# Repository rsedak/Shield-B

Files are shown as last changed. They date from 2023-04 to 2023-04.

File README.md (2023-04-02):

[Croatian version](README_HR-HR.md).

Introduction
============

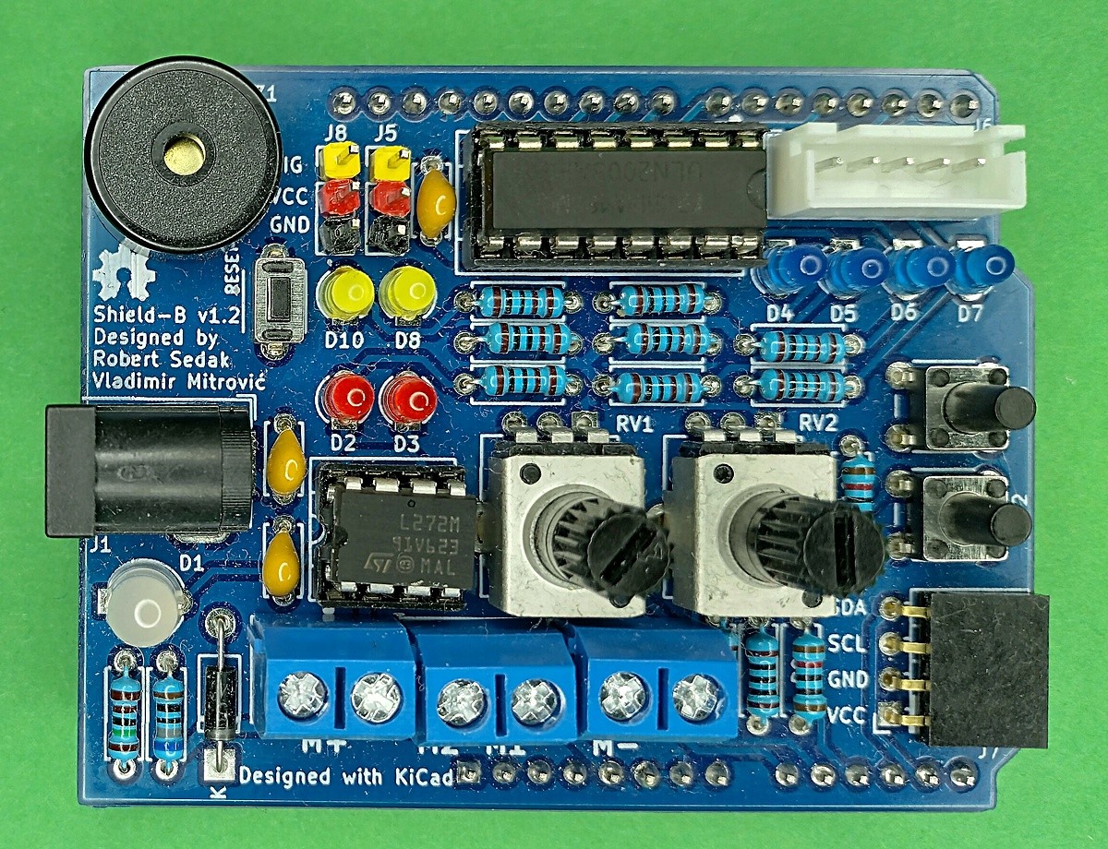
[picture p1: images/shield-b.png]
Shield application

Shield-B v1.2 is version of Arduino Uno based shield for student education compatible with BASCOM-AVR(C) and Arduino IDE.
During programming please keep in mind next design rules:
- D2, D4, D7, D8 — control step motor (J6)
- D5 — control DC motor (M1)
- D6 — control DC motor (M2)
- D9 — control servo motor (J5)
- D10 — control servo motor (J8)
- D13 — reserved for buzzer
- A0 — reserved for potentiometer RV1
- A1 — reserved for potentiometer RV2
- A2 — reserved for switch SW2 in INPUT_PULLUP mode
- A3 — reserved for switch SW3 INPUT_PULLUP mode
- A4,A5 — reserved for I2C communication with on board pull-up resistors (J7)

Contributors
------------
- Robert Sedak — features, Arduino expertise, schematic design, CAD design.
- Vladimir Mitrović — features, BASCOM-AVR expertise

Application
-----------
Robert Sedak made a video with examples programmed in Arduino IDE:

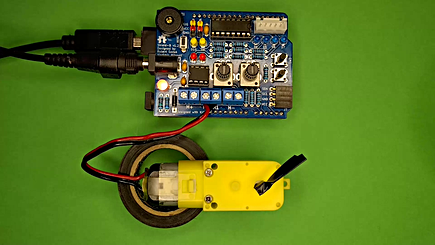
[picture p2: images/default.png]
Shield application (https://youtu.be/HcjEryUcfLM "Shield-B examples")


You can download examples for Arduino IDE from [here](examples/).

Bill Of Materials
-----------------
- 1 ea., PCB
- 1 ea., 680R ohm 1/4W 1% Resistor (R1)
- 8 ea., 1K ohm 1/4W 1% Resistor (R2-R8, R14)
- 2 ea., 10K ohm 1/4W 1% Resistor (R9, R10)
- 2 ea., 100R ohm 1/4W 1% Resistor (R11, R12)
- 1 ea., 1.5K ohm 1/4W 1% Resistor (R13)
- 1 ea., LED 5mm DUAL AKA (D1)
- 8 ea., LED 3mm (D2-D8, D10)
- 1 ea., 1N5817 (D9)
- 1 ea., 100nF (C1-C3)
- 1 ea., 14x7.5mm passive electronic piezoelectric buzzer SE (BZ1)
- 1 ea., Barrel Jack switch (J1)
- 3 ea., Screw terminal 2Pin (J2-J4)
- 2 ea., 1x3Pin 2.54mm Straight Pin Header - Black (J5, J8)
- 1 ea., Connector JST_XH_B5B-XH-A (J6)
- 1 ea., 1x4 pin 2.54mm Socket Connector - horizontal (J7)
- 2 ea., RV09 10K potentiometer - long shaft (RV1, RV2)
- 1 ea., 6x3x4.3mm SPST Momentary push switch (SW1)
- 2 ea., 6x6x10mm SPST Momentary push switch (SW1, SW2)
- 1 ea., 1x10Pin 2.54mm Straight Pin Header - Black
- 2 ea., 1x8Pin 2.54mm Straight Pin Header - Black
- 1 ea., 1x6Pin 2.54mm Straight Pin Header - Black
- 1 ea., 8 pin DIP Socket
- 1 ea., L272M
- 1 ea., 16 pin DIP Socket
- 1 ea., ULN2003

Design Files
------------
This project is designed using Open Source [KiCad](http://kicad.org/). Design files are located in the [design_files](design_files/) folder.  You can see the [schematic](images/shield-b_schematic.png).

Gerber files
------------
You can download gerber files from [here](gerber/shield_b_v1.2.zip).

Firmware
--------
This project can be programmed using the Open Source [Arduino](https://www.arduino.cc/) and [BASCOM-AVR(C)](https://www.mcselec.com/index.php?option=com_content&task=view&id=14&Itemid=103).
Arduino examples are located in [examples](examples/) folder.

License
-------
[Attribution-ShareAlike 4.0 International (CC BY-SA 4.0)](https://creativecommons.org/licenses/by-sa/4.0/)

You are free to:
- Share — copy and redistribute the material in any medium or format
- Adapt — remix, transform, and build upon the material

This license is acceptable for Free Cultural Works.
- The licensor cannot revoke these freedoms as long as you follow the license terms.

Under the following terms:
- Attribution — You must give appropriate credit, provide a link to the license, and indicate if changes were made. You may do so in any reasonable manner, but not in any way that suggests the licensor endorses you or your use.
- ShareAlike — If you remix, transform, or build upon the material, you must distribute your contributions under the same license as the original.

No additional restrictions — You may not apply legal terms or technological measures that legally restrict others from doing anything the license permits.

Reference Designs ARE PROVIDED "AS IS" AND "WITH ALL FAULTS". Authors DISCLAIMS ALL OTHER WARRANTIES, EXPRESS OR IMPLIED, REGARDING PRODUCTS, INCLUDING BUT NOT LIMITED TO, ANY IMPLIED WARRANTIES OF MERCHANTABILITY OR FITNESS FOR A PARTICULAR PURPOSE.
Authors may make changes to specifications and product descriptions at any time, without notice. The Customer must notrely on the absence or characteristics of any features or instructions marked "reserved" or "undefined." 
Authors reservesthese for future definition and shall have no responsibility whatsoever for conflicts or incompatibilities arising from future changes to them. The product information on the Web Site or Materials is subject to change without notice. Do not finalize a design with this info.

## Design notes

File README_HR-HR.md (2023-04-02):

[Engleska verzija](README.md). 

Uvod
============
Shield application
Shield-B v1.2 je učilo za programiranje mikropravljača Arduino Uno kompatibilno s BASCOM-AVR(C) i Arduino IDE.
Tijekom programiranja pridržavajte se sljedećih pravila:
- D2, D4, D7, D8 — kontrolira koračni motor
- D5 — controlira DC motor (M1)
- D5 — controlira DC motor (M2)
- D9 — controlira servo motor (J5)
- D9 — controlira servo motor (J8)
- D13 — je rezerviran za pasivnu piezo zujalicu
- A0 — je rezerviran za potenciometar RV1
- A1 — je rezerviran za potenciometar RV2
- A2 — je rezerviran za tipkalo SW2 u načinu rada INPUT_PULLUP
- A3 — je rezerviran za tipkalo SW3 u načinu rada INPUT_PULLUP
- A4,A5 — su rezervirani za komunikaciju preko I2C protokola, pull-up otpornici su na pločici

Autori
------------
- Robert Sedak — svojstva, prilagodba za Arduino, dizajn el. scheme, CAD dizajn.
- Vladimir Mitrović — svojstva, prilagodba za BASCOM-AVR

Application
-----------
Robert Sedak je snimio video s nekoliko primjera programiranim u Arduino IDE:

Shield application (https://youtu.be/HcjEryUcfLM "Shield-B examples")

Primjere za Arduino IDE možete preuzati [ovdje](examples/).

Popis komponenti
-----------------
- 1 ea., PCB
- 1 ea., 680 ohm 1/4W 1% otpornik (R1)
- 8 ea., 1K ohm 1/4W 1% otpornik R2-R8, R14)
- 2 ea., 10K ohm 1/4W 1% otpornik (R9, R10)
- 2 ea., 100 ohm 1/4W 1% otpornik (R11, R12)
- 1 ea., 1.5K ohm 1/4W 1% otpornik (R13)
- 1 ea., LED 5mm DUAL AKA (D1)
- 8 ea., LED 3mm (D2-D8, D10)
- 1 ea., 1N5817 (D9)
- 1 ea., 100nF (C1-C3)
- 1 ea., 14x7.5mm pasivna elektronička piezoe zujalica (BZ1)
- 1 ea., utičnica 3,5/1,4mm za PCB (J1)
- 3 ea., stezaljka za pločicu 2-polna (J2-J4)
- 2 ea., 1x6 pin 2.54mm Pin Header  (J5, J8)
- 1 ea., konektor JST_XH_B5B-XH-A (J6)
- 1 ea., 1x4 pin 2.54mm utičnica - vodoravna (J7)
- 2 ea., RV09 10K potenciometer - dugačka osovina (RV1, RV2)
- 1 ea., 6x3x4.3mm SPST tipkalo (SW1)
- 2 ea., 6x6x10mm SPST tipkalo (SW2, SW3)
- 1 ea., 1x10 pin 2.54mm Pin Header
- 2 ea., 1x8 pin 2.54mm Pin Header
- 1 ea., 1x6 pin 2.54mm Pin Header
- 1 ea., 8 pin DIP podnožje
- 1 ea., L272M
- 1 ea., 16 pin DIP podnožje
- 1 ea., ULN2003

Datoteke s dizajnom
------------
Ovo učilo je dizajnirano pomoću programa [KiCad](http://kicad.org/). Datoteke se nalaze u mapi [design_files](design_files/). Elekroničku schemu možete pogledati [ovdje](images/shield-b_schematic.png).

Gerber datoteke
------------
Gerber datoteke možete preuzeti [ovdje](gerber/shield_b_v1.2.zip).

Firmware
--------
Ovo učilo može biti progrmairano pomoću [Arduino IDE](https://www.arduino.cc/) i [BASCOM-AVR(C)](https://www.mcselec.com/index.php?option=com_content&task=view&id=14&Itemid=103).
Primjeri za Arduino IDS se nalaze u mapi [examples](examples/).

Licenca
-------
[Imenovanje-Dijeli pod istim uvjetima 4.0 međunarodna (CC BY-SA 4.0)](https://creativecommons.org/licenses/by-sa/4.0/deed.hr)

Slobodno možete:
- Dijelite dalje — možete umnažati i redistribuirati materijal u bilo kojem mediju ili formatu
-  Stvarajte prerade — možete remiksirati, mijenjati i prerađivati djelo u bilo koju svrhu, pa i komercijalnu

Davatelj licence ne može opozvati slobode korištenja koje Vam je ponudio dokle god se pridržavate uvjeta licence.

Pod sljedećim uvjetima:
- Imenovanje — Morate adekvatno navesti autora, uvrstiti link na licencu i naznačiti eventualne izmjene. Možete to učiniti na bilo koji razuman način, ali ne smijete sugerirati da davatelj licence izravno podupire Vas ili Vaše korištenje djela. 
- Dijeli pod istim uvjetima — Ako remiksirate, mijenjate ili prerađujete materijal, Vaše prerade morate distribuirati pod istom licencom pod kojom je bio izvornik. 

Bez daljnjih ograničenja — Ne smijete dodavati pravne uvjete ili tehnološke mjere zaštite koji će druge pravno ograničiti da čine ono što im licenca dopušta. 

Odricanje od odgovornosti
-------------------------
NAPOMENA - Dizajn je objavljen u dobroj namjeri i "takav kakav je" ("AS IS"), te sa mogućim greškama. Autori su kreirali učilo, slike, video i programski kod. Nama je radilo i uspjelo raditi na način kako je opisano, što ne znaći da će raditi i Vama. Ne odgovaramo ni za kakve posljedice koje mogu nastati prilikom korištenja učila, uputa ili programskog koda. Odričemo sve odgovorosti i jamstva- sami ste odgovorni za ono što radite i sami ste odgovorni što ste pristali pratiti i koristiti naše upute i informacije. 

Autori mogu mijenjati specifikacije i opise proizvoda u bilo kojem trenutku, bez prethodne obavijesti. Korisnik se ne smije osloniti na odsutnost ili karakteristike bilo kojih značajki ili uputa označenih kao "rezervirano" ili "nedefinirano".
Autori zadržavaju pravo budućih izmjena definicija i neće snositi nikakvu odgovornost za sukobe ili nekompatibilnosti koje proizlaze iz budućih promjena. Podaci o proizvodu na web stranici ili materijalima podložni su promjenama bez prethodne obavijesti. Nemojte finalizirati dizajn s ovim podacima. 

Reference Designs ARE PROVIDED "AS IS" AND "WITH ALL FAULTS". Authors DISCLAIMS ALL OTHER WARRANTIES, EXPRESS OR IMPLIED, REGARDING PRODUCTS, INCLUDING BUT NOT LIMITED TO, ANY IMPLIED WARRANTIES OF MERCHANTABILITY OR FITNESS FOR A PARTICULAR PURPOSE.
Authors may make changes to specifications and product descriptions at any time, without notice. The Customer must notrely on the absence or characteristics of any features or instructions marked "reserved" or "undefined." 
Authors reservesthese for future definition and shall have no responsibility whatsoever for conflicts or incompatibilities arising from future changes to them. The product information on the Web Site or Materials is subject to change without notice. Do not finalize a design with this info.

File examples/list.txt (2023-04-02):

Examples
001 Control DC motor with SW2 and SW3
002 Control DC motor with RV1
003 Control DC motor with RV1
004 Control servo motor with RV1
005 Control step motor with SW2 and SW3

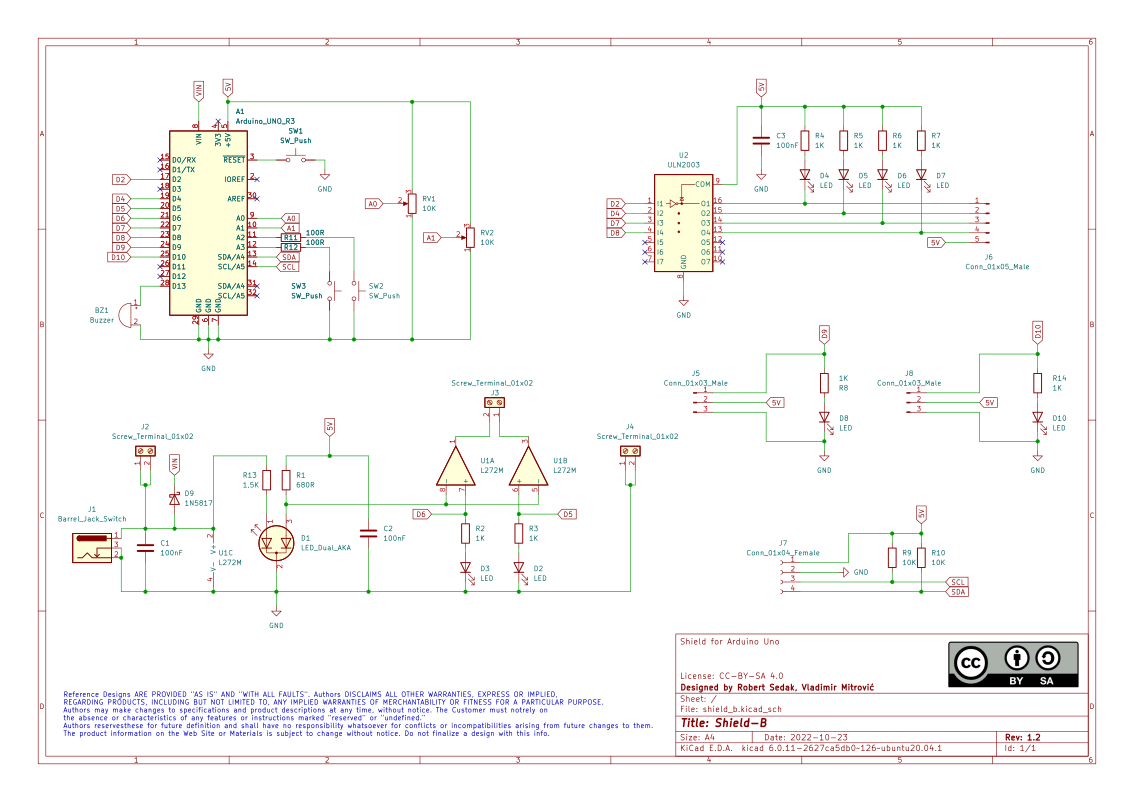
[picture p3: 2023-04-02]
images/shield-b_schematic.png

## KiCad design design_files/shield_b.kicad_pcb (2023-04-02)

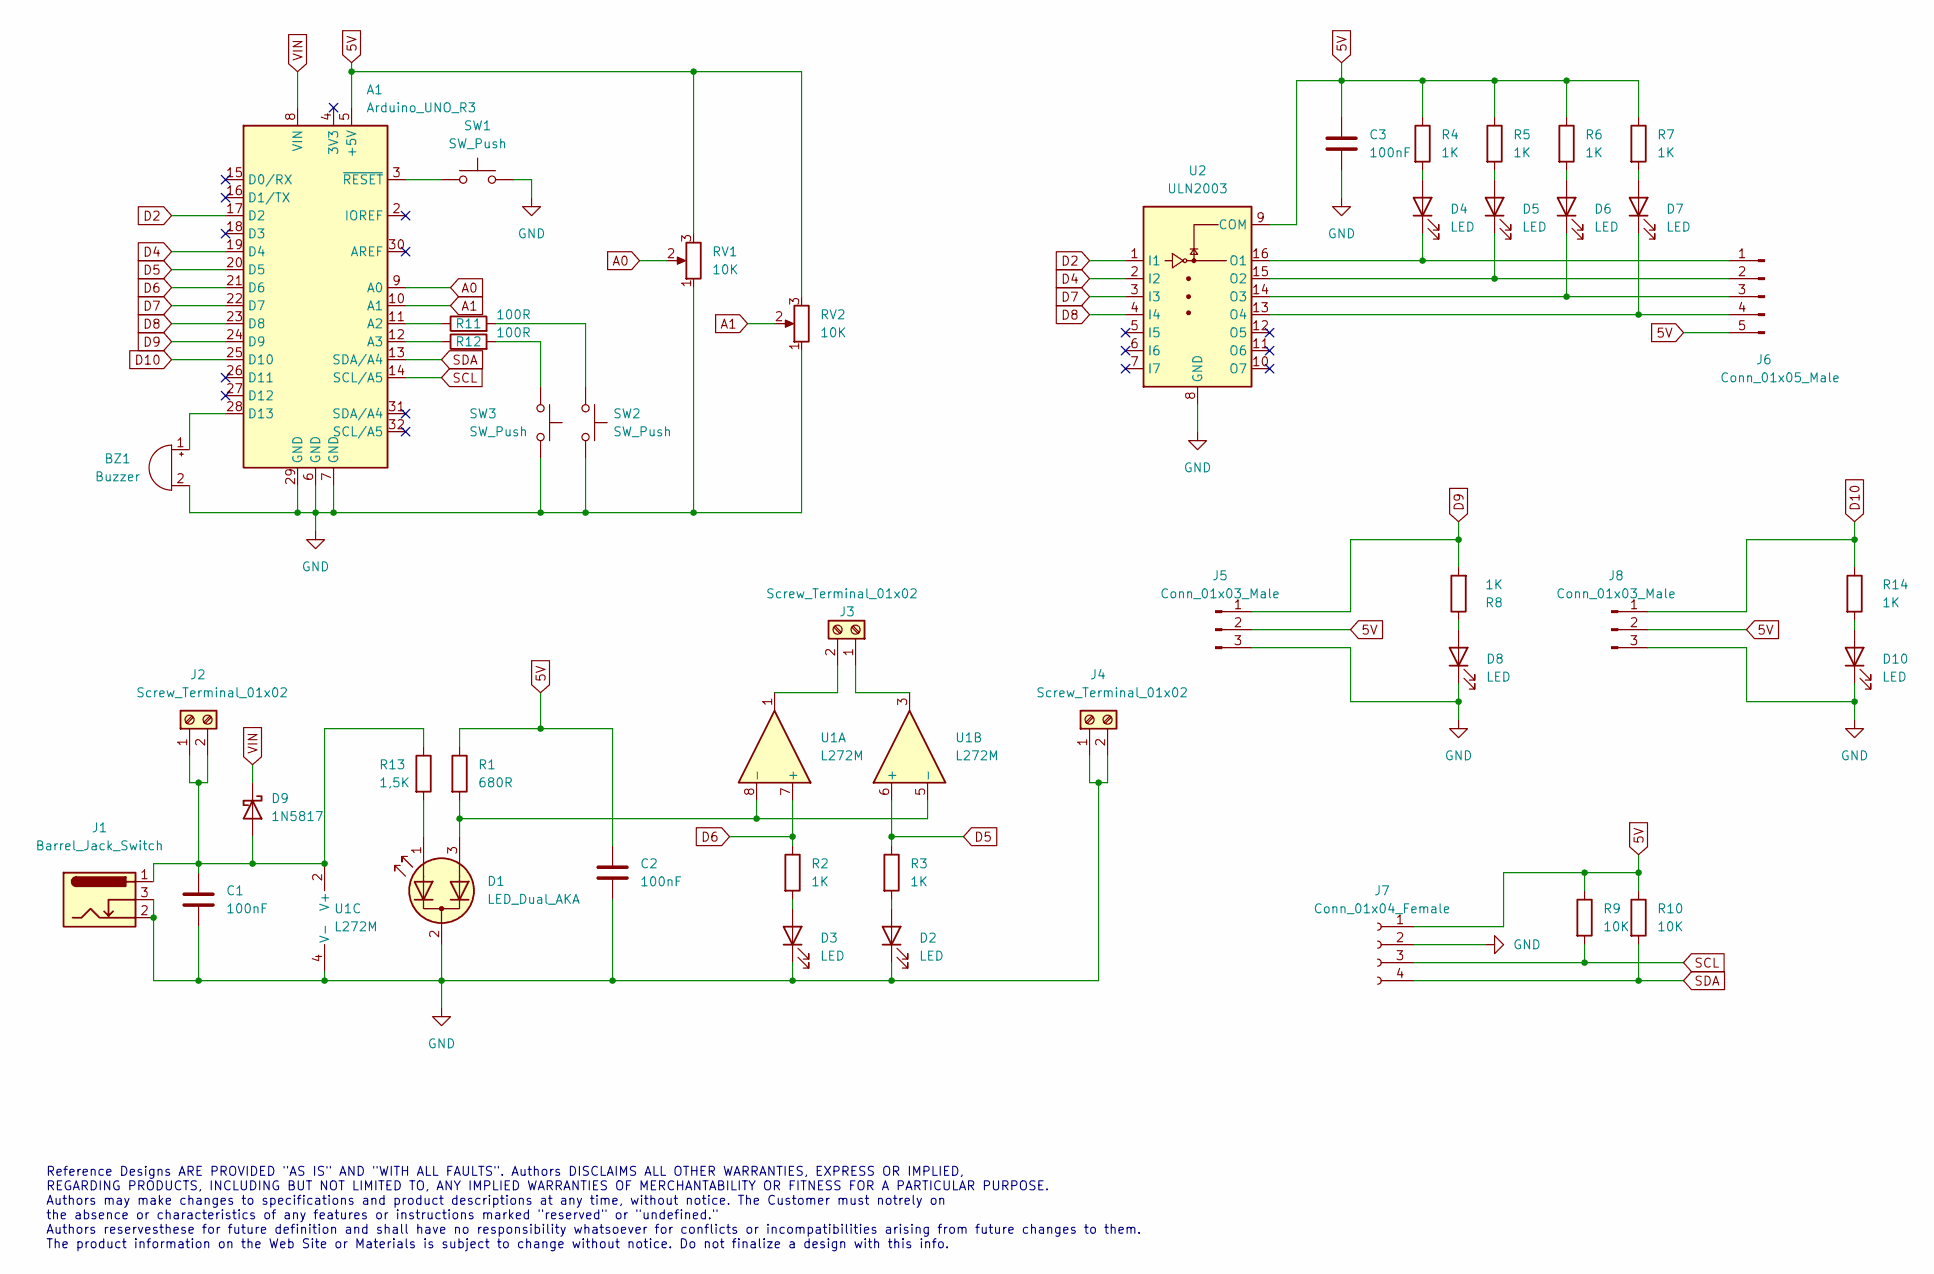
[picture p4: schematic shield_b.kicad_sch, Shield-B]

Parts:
A1: Arduino_UNO_R3
BZ1: Buzzer; Buzzer_12x9.5RM7.6_5
C1, C2, C3: 100nF; C_Disc_D5.0mm_W2.5mm_P5.00mm
D1: LED_Dual_AKA; LED_D5.0mm-3
D2, D3, D4, D5, D6, D7, D8, D10: LED; LED_D3.0mm
D9: 1N5817; D_DO-41_SOD81_P10.16mm_Horizontal
J1: Barrel_Jack_Switch; BarrelJack_GCT_DCJ200-10-A_Horizontal
J2, J3, J4: Screw_Terminal_01x02; TerminalBlock_bornier-2_P5.08mm
J5, J8: Conn_01x03_Male; PinHeader_1x03_P2.54mm_Vertical
J6: Conn_01x05_Male; JST_XH_B5B-XH-A_1x05_P2.50mm_Vertical
J7: Conn_01x04_Female; PinSocket_1x04_P2.54mm_Horizontal
R1: 680R; R_Axial_DIN0207_L6.3mm_D2.5mm_P7.62mm_Horizontal
R2, R3, R4, R5, R6, R7, R8, R14: 1K; R_Axial_DIN0207_L6.3mm_D2.5mm_P7.62mm_Horizontal
R9, R10: 10K; R_Axial_DIN0207_L6.3mm_D2.5mm_P7.62mm_Horizontal
R11, R12: 100R; R_Axial_DIN0207_L6.3mm_D2.5mm_P7.62mm_Horizontal
R13: 1,5K; R_Axial_DIN0207_L6.3mm_D2.5mm_P7.62mm_Horizontal
RV1, RV2: 10K; Potentiometer_Alpha_RV09ACF-40_Single_Vertical
SW1: SW_Push; SW_PUSH_3x6x5mm
SW2, SW3: SW_Push; SW_PUSH_6mm
U1: L272M; DIP-8_W7.62mm_Socket
U2: ULN2003; DIP-16_W7.62mm_Socket

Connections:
5V: A1.5 (+5V), C2.1, C3.2, J5.2, J6.5, J7.1, J8.2, R1.1, R4.1, R5.1, R6.1, R7.1, R9.1, R10.1, RV1.3, RV2.3, U2.9 (COM)
A0: A1.9 (A0), RV1.2
A1: A1.10 (A1), RV2.2
D2: A1.17 (D2), U2.1 (I1)
D4: A1.19 (D4), U2.2 (I2)
D5: A1.20 (D5), R3.1, U1.6 (+)
D6: A1.21 (D6), R2.1, U1.7 (+)
D7: A1.22 (D7), U2.3 (I3)
D8: A1.23 (D8), U2.4 (I4)
D9: A1.24 (D9), J5.1, R8.2
D10: A1.25 (D10), J8.1, R14.1
GND: A1.6 (GND), A1.7 (GND), A1.29 (GND), BZ1.2 (+), C1.2, C2.2, C3.1, D1.2 (K), D2.1 (K), D3.1 (K), D8.1 (K), D10.1 (K), J1.2, J1.3, J4.1, J4.2, J5.3, J7.2, J8.3, RV1.1, RV2.1, SW1.2, SW2.2, SW3.2, U1.4 (V-), U2.8 (GND)
unnamed: A1.3 (~RESET), SW1.1
unnamed: A1.11 (A2), R11.1
unnamed: A1.12 (A3), R12.1
unnamed: A1.28 (D13), BZ1.1 (-)
unnamed: C1.1, D9.2 (A), J1.1, J2.1, J2.2, R13.1, U1.2 (V+)
unnamed: D1.1 (A1), R13.2
unnamed: D1.3 (A2), R1.2, U1.5 (-), U1.8 (-)
unnamed: D2.2 (A), R3.2
unnamed: D3.2 (A), R2.2
unnamed: D4.1 (K), J6.1, U2.16 (O1)
unnamed: D4.2 (A), R4.2
unnamed: D5.1 (K), J6.2, U2.15 (O2)
unnamed: D5.2 (A), R5.2
unnamed: D6.1 (K), J6.3, U2.14 (O3)
unnamed: D6.2 (A), R6.2
unnamed: D7.1 (K), J6.4, U2.13 (O4)
unnamed: D7.2 (A), R7.2
unnamed: D8.2 (A), R8.1
unnamed: D10.2 (A), R14.2
unnamed: J3.1, U1.3
unnamed: J3.2, U1.1
unnamed: R11.2, SW2.1
unnamed: R12.2, SW3.1
SCL: A1.14 (SCL/A5), J7.3, R9.2
SDA: A1.13 (SDA/A4), J7.4, R10.2
VIN: A1.8 (VIN), D9.1 (K)

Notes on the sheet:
Reference Designs ARE PROVIDED "AS IS" AND "WITH ALL FAULTS". Authors DISCLAIMS ALL OTHER WARRANTIES, EXPRESS OR IMPLIED, REGARDING PRODUCTS, INCLUDING BUT NOT LIMITED TO, ANY IMPLIED WARRANTIES OF MERCHANTABILITY OR FITNESS FOR A PARTICULAR PURPOSE. Authors may make changes to specifications and p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

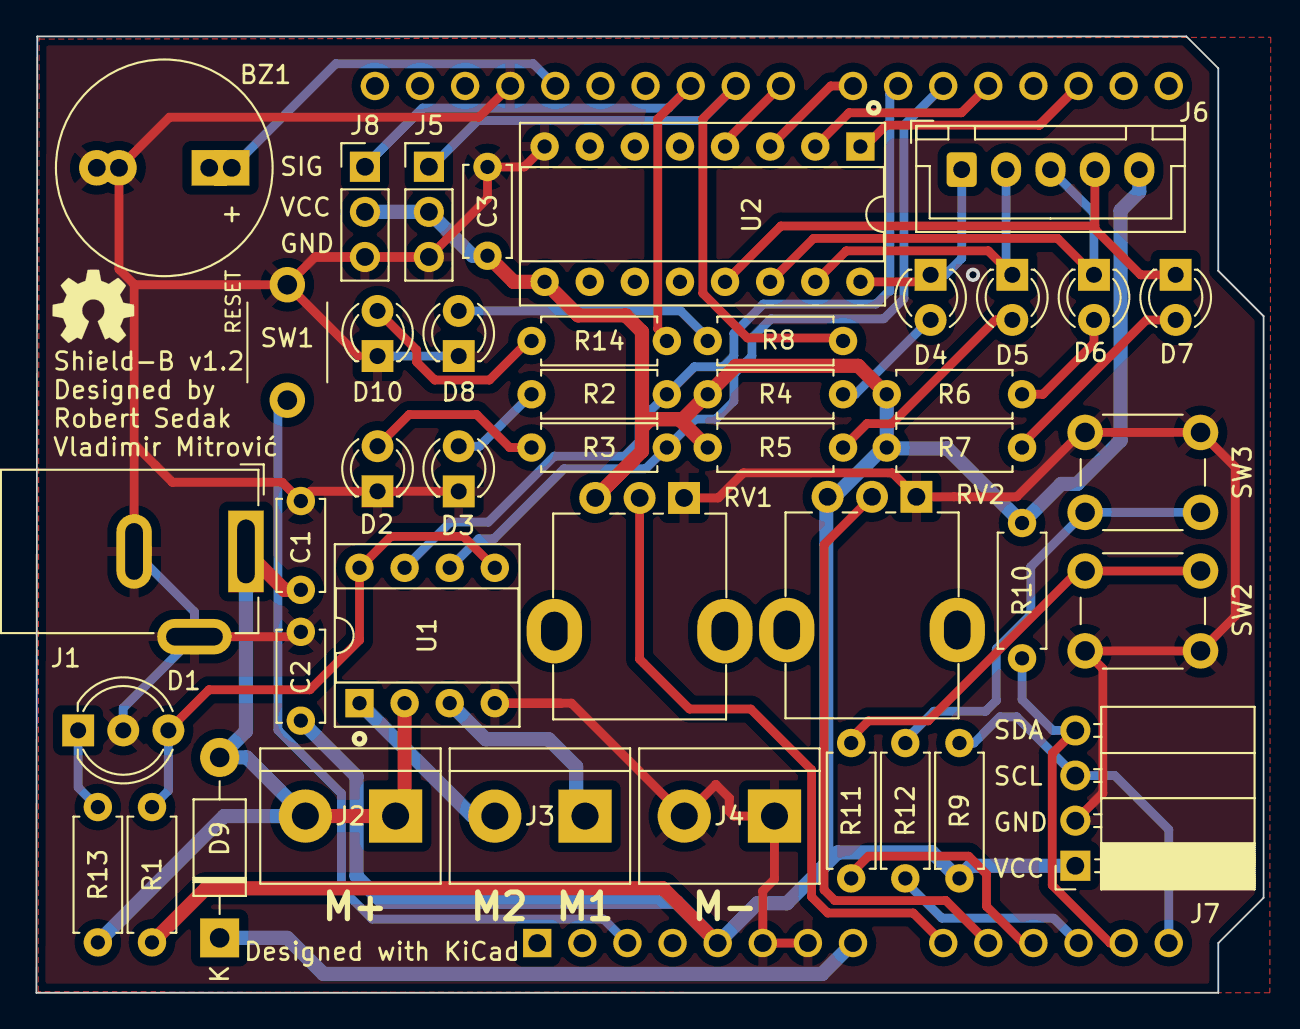
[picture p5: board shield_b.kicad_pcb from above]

Board: 2 copper layers, 69.1 x 53.8 mm, 45 parts (1 on the bottom side), 38 nets.

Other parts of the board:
OSHW Logo: OSHW-Logo_6x6mm_SilkScreen

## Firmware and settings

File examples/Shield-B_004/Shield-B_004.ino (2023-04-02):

/* Control servo motor with RV1
 *  
 * Connect servo motor to J5 connector
 * 
 * Created 2022 by Robert Sedak
 * 
 * This example code is in the public domain.
 *  
 *  THE SOFTWARE IS PROVIDED "AS IS", WITHOUT WARRANTY OF ANY KIND, 
 *  EXPRESS OR IMPLIED, INCLUDING BUT NOT LIMITED TO THE WARRANTIES 
 *  OF MERCHANTABILITY, FITNESS FOR A PARTICULAR PURPOSE AND 
 *  NONINFRINGEMENT. IN NO EVENT SHALL THE AUTHOR(S) OR 
 *  CONTRIBUTOR(S) BE LIABLE FOR ANY CLAIM, DAMAGES OR OTHER 
 *  LIABILITY, WHETHER IN AN ACTION OF CONTRACT, TORT OR OTHERWISE, 
 *  ARISING FROM, OUT OF OR IN CONNECTION WITH THE SOFTWARE OR 
 *  THE USE OR OTHER DEALINGS IN THE SOFTWARE.
 */

#include <Servo.h>

Servo S1;

void setup() {
  S1.attach(9);
}

void loop() {
  int Rv1 = analogRead(A0);
  Rv1 = map(Rv1, 0, 1023, 0, 180);
  S1.write(Rv1);

  delay(15);
}

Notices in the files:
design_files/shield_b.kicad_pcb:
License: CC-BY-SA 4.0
